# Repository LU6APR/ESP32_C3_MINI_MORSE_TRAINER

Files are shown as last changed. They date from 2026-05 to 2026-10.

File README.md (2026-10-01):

# ESP32_C3_MINI_MORSE_TRAINER
ESP32 C3 MINI MORSE TRAINER / OSCILATOR FOR IAMBIC KEYS

Keyer Iámbico + Decodificador CW con ESP32-C3 Mini
 Autor: LU6APR Pablo Ramos.
________________________________________
1. DESCRIPCIÓN DEL PROYECTO
Este proyecto consiste en la construcción de un Keyer Iámbico electrónico con decodificador de código Morse integrado, basado en el microcontrolador ESP32-C3 Super Mini.
El dispositivo permite:
•	Transmitir código Morse mediante una paleta iámbica (dos palancas: punto y raya)
•	Decodificar automáticamente el código Morse enviado
•	Mostrar el texto decodificado en una pantalla OLED (4 líneas)
•	Ajustar la velocidad de transmisión (WPM)
•	Espaciado automático después de 1 segundo de pausa
•	Borrado automático de pantalla al completar 4 líneas
•	Borrado manual con pulsación corta del botón

circuit_image

Copiar codigo en arduino ide, seleccionar puerto y ESP32 C3 mini, en mi caso use el LOLIN C3 MINI, compilar y subir al esp32 c3 mini.

Nota: el proyecto puede armarse sin la pantalla, y aun funcionara como oscilador para keys iambicos...

14/8/2026

<strong>LU5DZY</strong>, comparte circuito con opto acoplador al tx, por recomendacion en grupo de CW de colegas/amigos.
abajo el circuito. Grcs Nico!

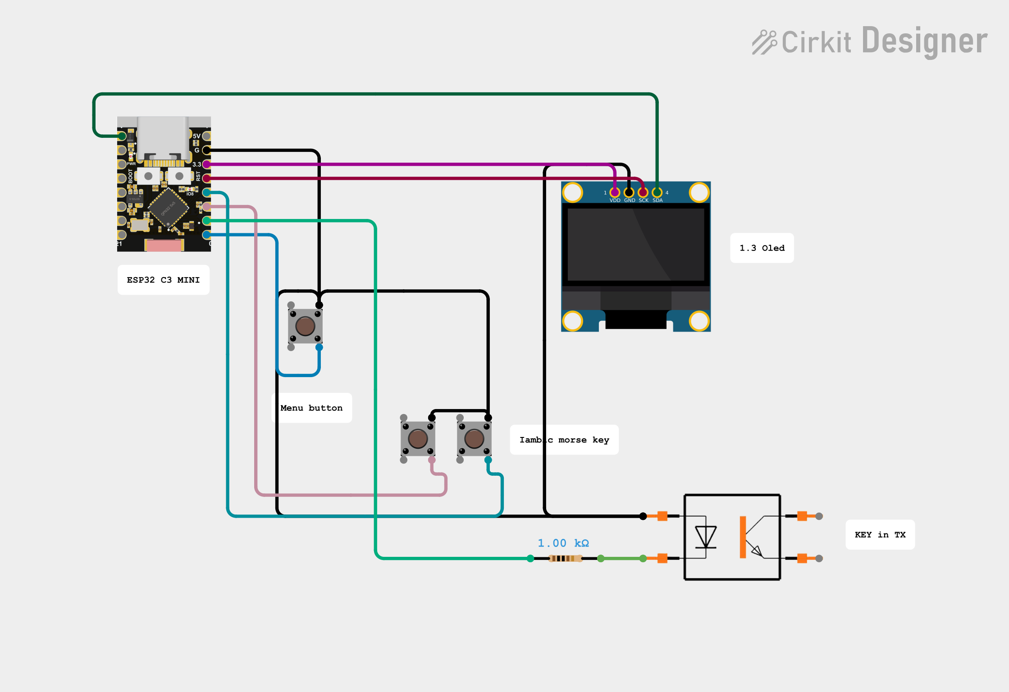
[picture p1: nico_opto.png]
circuit_image


Video: [LU5DZY_Opto.mp4](LU5DZY_Opto.mp4)

29/9/2026

<strong>PY3DU</strong>, comparte mejora en la seleccion de velocidad tocando boton y paddles para subir o bajar velocidad.
Disponible en la seccion de releases...

Video: [PY3DU_SPEED_CHANGE.mp4](PY3DU_spd_chng.mp4)

30/9/2026

<strong>LU6APR</strong>, Se convierte libreria de video a U8g2lib.h con la mejora en la seleccion de velocidad tocando boton y paddles para subir o bajar velocidad propuesta por PY3DU.
Disponible en la seccion de releases...

30/9/2026

<strong>PY3DU</strong>, comparte nueva mejora: escucha y repite y en la seleccion de velocidad tocando boton y paddles para subir o bajar velocidad.
Disponible en la seccion de releases...
 
Video: [PY3DU_game_listening.mp4](PY3DU_game_listening.mp4)

1/10/2026

<strong>PY3DU</strong>, comparte cambio de  salida de buzzer por  un parlante de 32 ohms.

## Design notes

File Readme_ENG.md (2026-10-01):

# ESP32_C3_MINI_MORSE_TRAINER
ESP32 C3 MINI MORSE TRAINER / OSCILLATOR FOR IAMBIC KEYS

Iambic Keyer + CW Decoder with ESP32-C3 Mini
 Author: LU6APR Pablo Ramos.
________________________________________
1. PROJECT DESCRIPTION
This project consists of building an electronic Iambic Keyer with an integrated Morse code decoder, based on the ESP32-C3 Super Mini microcontroller.
The device allows:
•	Transmitting Morse code using an iambic paddle (two levers: dot and dash)
•	Automatically decoding the transmitted Morse code
•	Displaying the decoded text on an OLED screen (4 lines)
•	Adjusting the transmission speed (WPM)
•	Automatic spacing after 1 second of pause
•	Automatic screen clearing when 4 lines are completed
•	Manual clearing with a short button press

circuit_image

Copy the code into the Arduino IDE, select the port and the ESP32 C3 mini (in my case I used the LOLIN C3 MINI), compile and upload it to the ESP32 C3 mini.

Note: the project can be assembled without the display, and it will still work as an oscillator for iambic keys...

14/8/2026

<strong>LU5DZY</strong> shared a circuit with an optocoupler to the TX, following a recommendation in a CW group of colleagues/friends.
The circuit is below. Thanks Nico!

circuit_image

Video: [LU5DZY_Opto.mp4](LU5DZY_Opto.mp4)

29/9/2026

<strong>PY3DU</strong>, Improved speed selection: now you can adjust it either by pressing the button or using the paddles (dits and dahs) to increase or decrease the speed. Thanks, Luiz! PY3DU.
Available in  releases...

Video: [PY3DU_SPEED_CHANGE.mp4](PY3DU_spd_chng.mp4)

30/9/2026

<strong>LU6APR</strong> The video library has been updated to U8g2lib.h  with the improvement in speed selection, allowing adjustment by pressing the button or using the paddles to increase or decrease the speed, as proposed by PY3DU. Available in the releases section...

01/10/2026

<strong>PY3DU</strong>, share an output with 32 ohms speaker replacing the buzzer.

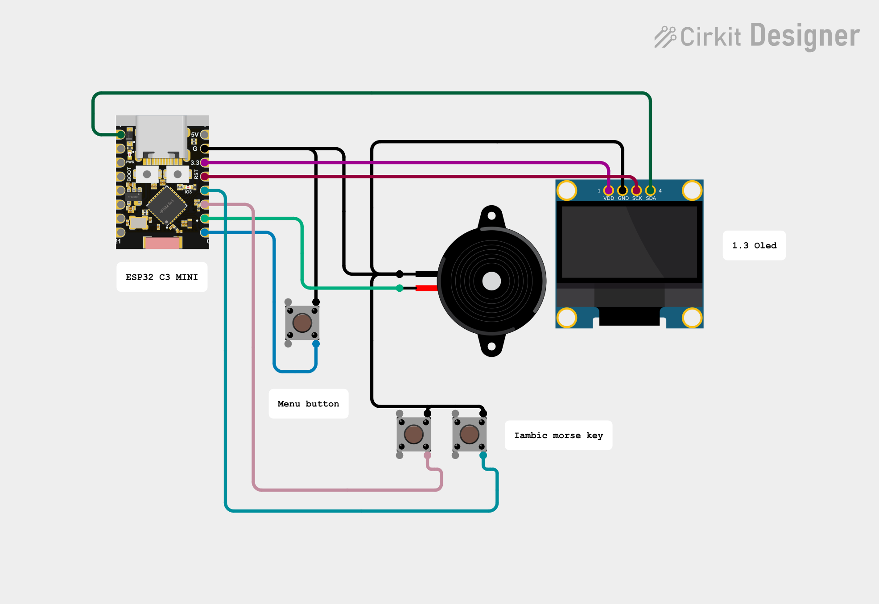
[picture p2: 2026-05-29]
circuit_image.png

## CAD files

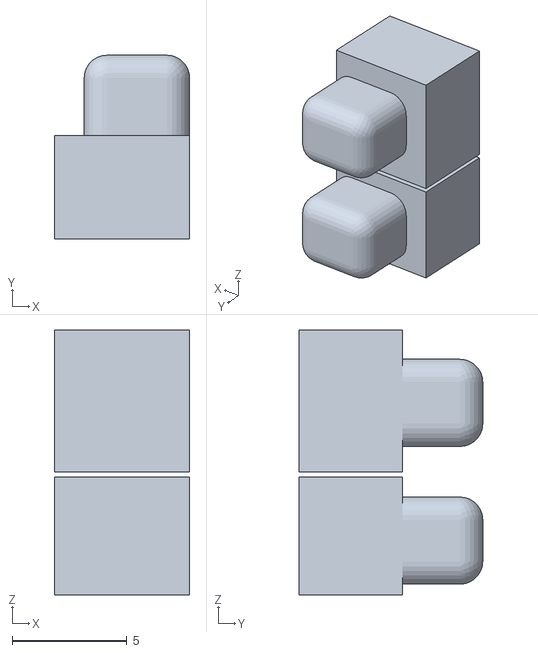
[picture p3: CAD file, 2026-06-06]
botones.stl
5.90 x 8.00 x 11.5

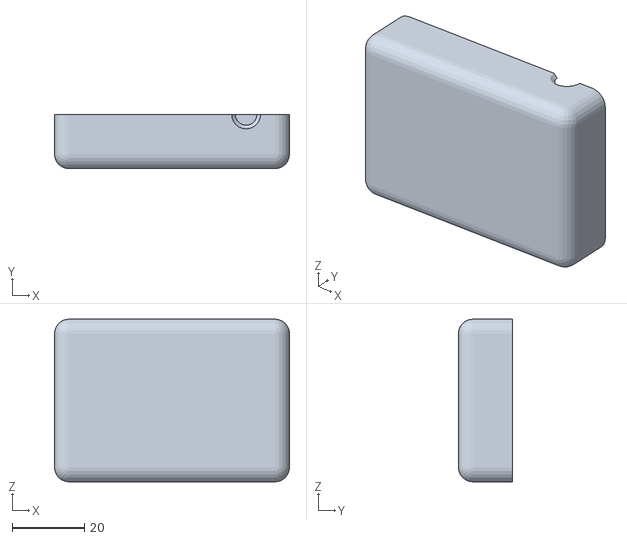
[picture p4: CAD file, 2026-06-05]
part2.stl
65.0 x 15.0 x 45.0

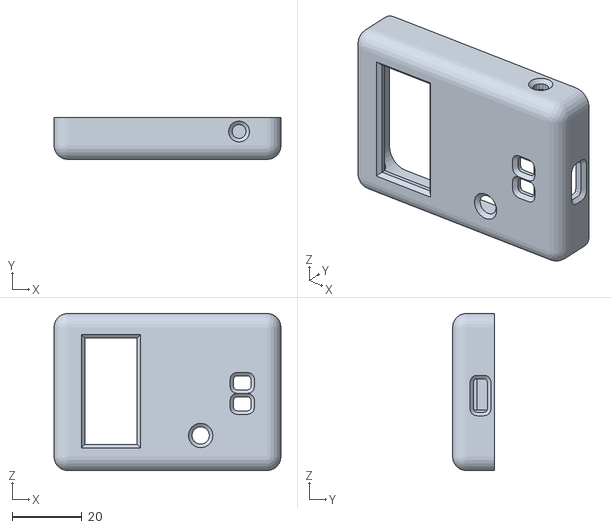
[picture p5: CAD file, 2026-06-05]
Part1.stl
65.0 x 12.0 x 45.0

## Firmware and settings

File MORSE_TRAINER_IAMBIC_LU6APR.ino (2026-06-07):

/*
  KEYER IÁMBICO LU6APR + DECODIFICADOR CW para ESP32-C3 Mini
  Pausa de 1 segundo para espacio automático
  Auto clear al llenar 4 líneas
*/

#include <Wire.h>
#include <U8g2lib.h>
#include <EEPROM.h>

// ==========================================
//   CONFIGURACIÓN DE PINES
// ==========================================
#define PIN_DIT         2
#define PIN_DAH         3
#define PIN_COMMAND     0
#define PIN_SIDETONE    1
#define PIN_KEY_OUT     6

#define I2C_SDA         5
#define I2C_SCL         4

// ==========================================
//   DISPLAY
// ==========================================
U8G2_SH1106_128X64_NONAME_F_HW_I2C u8g2(U8G2_R0, U8X8_PIN_NONE);

// ==========================================
//   CONFIGURACIÓN
// ==========================================
struct KeyerSettings {
  uint8_t speedWPM;
  bool iambicModeA;
  bool swapPaddles;
  bool sidetoneEnabled;
  uint16_t sidetoneFreq;
};

KeyerSettings settings = {15, true, false, true, 600};

// ==========================================
//   TABLA MORSE
// ==========================================
struct MorseChar {
  char character;
  uint8_t length;
  uint32_t code;
};

const MorseChar morseTable[] PROGMEM = {
  {'A',2,0b01},{'B',4,0b1000},{'C',4,0b1010},{'D',3,0b100},{'E',1,0b0},
  {'F',4,0b0010},{'G',3,0b110},{'H',4,0b0000},{'I',2,0b00},{'J',4,0b0111},
  {'K',3,0b101},{'L',4,0b0100},{'M',2,0b11},{'N',2,0b10},{'O',3,0b111},
  {'P',4,0b0110},{'Q',4,0b1101},{'R',3,0b010},{'S',3,0b000},{'T',1,0b1},
  {'U',3,0b001},{'V',4,0b0001},{'W',3,0b011},{'X',4,0b1001},{'Y',4,0b1011},
  {'Z',4,0b1100},{'0',5,0b11111},{'1',5,0b01111},{'2',5,0b00111},{'3',5,0b00011},
  {'4',5,0b00001},{'5',5,0b00000},{'6',5,0b10000},{'7',5,0b11000},{'8',5,0b11100},
  {'9',5,0b11110},{'.',6,0b010101},{',',6,0b110011},{'?',6,0b001100},{'!',6,0b101011},
  {';',6,0b101010},{':',6,0b111000},{'\'',6,0b011110},{'"',6,0b010110},{'-',6,0b100001},
  {'/',5,0b10010},{'=',5,0b10001},{'(',5,0b10110},{')',6,0b101101},{'@',6,0b110110},
  {'_',6,0b100110},{'+',5,0b01010},{'&',5,0b01000}
};

// ==========================================
//   VARIABLES
// ==========================================
#define MAX_TEXT_LENGTH 200
char textBuffer[MAX_TEXT_LENGTH];
uint16_t bufferStart = 0, bufferEnd = 0;
bool bufferFull = false;

uint32_t currentCode = 0;
uint8_t currentLength = 0;
unsigned long lastChangeTime = 0;
bool isKeyDown = false;
unsigned long keyDownStart = 0;

unsigned long lastKeyActivityTime = 0;
bool espacioAgregadoPorPausa = false;
const unsigned long PAUSA_ESPACIO_MS = 1000;

enum KeyerState { IDLE, DIT_PENDING, DAH_PENDING, KEY_DOWN, INTER_ELEMENT };
KeyerState keyerState = IDLE;
unsigned long keyerTimer = 0;
bool txActive = false;
volatile uint8_t paddleState = 0;
const uint8_t DIT_MASK = 0x01, DAH_MASK = 0x02;

bool lastBtnState = HIGH;
#define MAX_PANTALLA_CHARS 80
int caracteresEnPantalla = 0;

// ==========================================
//   FUNCIONES
// ==========================================
unsigned long getDitDuration() { return 1200UL / settings.speedWPM; }
unsigned long getDahDuration() { return getDitDuration() * 3; }
unsigned long getInterLetterGap() { return getDitDuration() * 3; }
unsigned long getInterWordGap() { return getDitDuration() * 7; }

void updateDisplay();

void addCharToBuffer(char c) {
  if (bufferFull) {
    textBuffer[bufferEnd] = c;
    bufferEnd = (bufferEnd + 1) % MAX_TEXT_LENGTH;
    bufferStart = bufferEnd;
    caracteresEnPantalla = MAX_PANTALLA_CHARS;
  } else {
    textBuffer[bufferEnd] = c;
    bufferEnd = (bufferEnd + 1) % MAX_TEXT_LENGTH;
    if (bufferEnd == bufferStart) bufferFull = true;
    caracteresEnPantalla++;
  }
  updateDisplay();
}

void addSpaceToBuffer() {
  if (bufferEnd != bufferStart || !bufferFull) addCharToBuffer(' ');
}

void clearBuffer() {
  bufferStart = 0; bufferEnd = 0; bufferFull = false;
  caracteresEnPantalla = 0;
  memset(textBuffer, 0, MAX_TEXT_LENGTH);
  updateDisplay();
}

void updateDisplay() {
  u8g2.firstPage();
  do {
    u8g2.setFont(u8g2_font_6x10_tf);
    uint16_t idx = bufferStart;
    for (int line = 0; line < 4; line++) {
      char lineBuffer[21] = {0};
      int col = 0;
      while (col < 20 && (idx != bufferEnd || bufferFull)) {
        char c = textBuffer[idx];
        if (c == '\0') c = ' ';
        lineBuffer[col++] = c;
        idx = (idx + 1) % MAX_TEXT_LENGTH;
        if (idx == bufferStart && !bufferFull) break;
      }
      u8g2.drawStr(0, 12 + (line * 12), lineBuffer);
    }
    char statusLine[25];
    sprintf(statusLine, "%dWPM %s", settings.speedWPM,
            settings.iambicModeA ? "IAM-A" : "IAM-B");
    u8g2.setFont(u8g2_font_5x7_tf);
    u8g2.drawStr(0, 58, statusLine);
  } while (u8g2.nextPage());
}

char decodeMorse(uint32_t code, uint8_t length) {
  int num = sizeof(morseTable) / sizeof(morseTable[0]);
  for (int i = 0; i < num; i++) {
    MorseChar mc;
    memcpy_P(&mc, &morseTable[i], sizeof(mc));
    if (mc.length == length && mc.code == code) return mc.character;
  }
  return '?';
}

void verificarPausaLarga() {
  if (!txActive && !isKeyDown) {
    if ((millis() - lastKeyActivityTime) >= PAUSA_ESPACIO_MS && !espacioAgregadoPorPausa) {
      addSpaceToBuffer();
      espacioAgregadoPorPausa = true;
      // BEEP ELIMINADO - Ya no suena al agregar espacio
    }
  } else {
    espacioAgregadoPorPausa = false;
  }
}

void verificarAutoClear() {
  if (caracteresEnPantalla >= MAX_PANTALLA_CHARS) {
    clearBuffer();
    const char* msg = ">CLEAR<";
    for (const char* p = msg; *p; p++) addCharToBuffer(*p);
    if (settings.sidetoneEnabled) {
      tone(PIN_SIDETONE, 1000); delay(60); noTone(PIN_SIDETONE);
      delay(40);
      tone(PIN_SIDETONE, 1200); delay(60); noTone(PIN_SIDETONE);
    }
  }
}

void processDecoder() {
  bool currentKeyState = digitalRead(PIN_KEY_OUT);
  unsigned long now = millis();
  
  if (currentKeyState && !isKeyDown) {
    isKeyDown = true; keyDownStart = now; lastKeyActivityTime = now;
    if (currentLength > 0 && (now - lastChangeTime) > getInterLetterGap()) {
      char c = decodeMorse(currentCode, currentLength);
      if (c != '\0') addCharToBuffer(c);
      currentCode = 0; currentLength = 0;
    }
  } else if (!currentKeyState && isKeyDown) {
    isKeyDown = false;
    unsigned long duration = now - keyDownStart;
    unsigned long ditDur = getDitDuration();
    lastKeyActivityTime = now;
    if (duration <= ditDur * 1.5) {
      currentCode = (currentCode << 1) | 0;
    } else if (duration <= ditDur * 3.5) {
      currentCode = (currentCode << 1) | 1;
    } else {
      currentCode = 0; currentLength = 0;
    }
    if (duration <= ditDur * 3.5) { currentLength++; if (currentLength > 12) currentLength = 12; }
    lastChangeTime = now;
  } else if (!isKeyDown && currentLength > 0) {
    if ((now - lastChangeTime) >= getInterLetterGap()) {
      char c = decodeMorse(currentCode, currentLength);
      if (c != '\0') addCharToBuffer(c);
      currentCode = 0; currentLength = 0; lastChangeTime = now;
    }
    if ((now - lastChangeTime) >= getInterWordGap()) {
      if (bufferEnd == 0 || textBuffer[(bufferEnd - 1 + MAX_TEXT_LENGTH) % MAX_TEXT_LENGTH] != ' ') {
        addSpaceToBuffer();
      }
      lastChangeTime = now;
    }
  }
  verificarPausaLarga();
  verificarAutoClear();
}

uint8_t readPaddles() {
  uint8_t result = 0;
  if (digitalRead(PIN_DIT) == LOW) result |= 0x01;
  if (digitalRead(PIN_DAH) == LOW) result |= 0x02;
  if (result) { lastKeyActivityTime = millis(); espacioAgregadoPorPausa = false; }
  if (settings.swapPaddles) {
    uint8_t swapped = 0;
    if (result & 0x01) swapped |= 0x02;
    if (result & 0x02) swapped |= 0x01;
    return swapped;
  }
  return result;
}

void startTransmit() {
  if (!txActive) {
    txActive = true;
    digitalWrite(PIN_KEY_OUT, HIGH);
    if (settings.sidetoneEnabled) tone(PIN_SIDETONE, settings.sidetoneFreq);
  }
}

void stopTransmit() {
  if (txActive) {
    txActive = false;
    digitalWrite(PIN_KEY_OUT, LOW);
    if (settings.sidetoneEnabled) noTone(PIN_SIDETONE);
  }
}

void processKeyer() {
  uint8_t paddles = readPaddles();
  unsigned long now = millis();
  switch (keyerState) {
    case IDLE:
      if (paddles & 0x01) { paddleState |= 0x01; keyerState = DIT_PENDING; }
      else if (paddles & 0x02) { paddleState |= 0x02; keyerState = DAH_PENDING; }
      break;
    case DIT_PENDING:
      if (paddleState & 0x01) { startTransmit(); keyerTimer = now + getDitDuration(); keyerState = KEY_DOWN; paddleState &= ~0x01; }
      else if (paddles & 0x02) { paddleState |= 0x02; keyerState = DAH_PENDING; }
      else keyerState = IDLE;
      break;
    case DAH_PENDING:
      if (paddleState & 0x02) { startTransmit(); keyerTimer = now + getDahDuration(); keyerState = KEY_DOWN; paddleState &= ~0x02; }
      else if (paddles & 0x01) { paddleState |= 0x01; keyerState = DIT_PENDING; }
      else keyerState = IDLE;
      break;
    case KEY_DOWN:
      if (now >= keyerTimer) { stopTransmit(); keyerTimer = now + getDitDuration(); keyerState = INTER_ELEMENT; if (!settings.iambicModeA) { uint8_t np = readPaddles(); if (np & 0x01) paddleState |= 0x01; if (np & 0x02) paddleState |= 0x02; } }
      break;
    case INTER_ELEMENT:
      if (now >= keyerTimer) {
        if (paddleState & 0x01) keyerState = DIT_PENDING;
        else if (paddleState & 0x02) keyerState = DAH_PENDING;
        else { uint8_t np = readPaddles(); if (np & 0x01) { paddleState |= 0x01; keyerState = DIT_PENDING; } else if (np & 0x02) { paddleState |= 0x02; keyerState = DAH_PENDING; } else keyerState = IDLE; }
      }
      break;
  }
}

void processCommand() {
  bool btnState = digitalRead(PIN_COMMAND);
  if (lastBtnState == HIGH && btnState == LOW) {
    unsigned long pressStart = millis();
    while (digitalRead(PIN_COMMAND) == LOW) delay(10);
    unsigned long duracion = millis() - pressStart;
    if (duracion < 1000) {
      clearBuffer();
      if (settings.sidetoneEnabled) { tone(PIN_SIDETONE, 800); delay(80); noTone(PIN_SIDETONE); }
    } else {
      settings.speedWPM += 5;
      if (settings.speedWPM > 35) settings.speedWPM = 10;
      EEPROM.begin(sizeof(settings) + 4);
      EEPROM.put(4, settings);
      EEPROM.commit();
      EEPROM.end();
      clearBuffer();
      char msg[8];
      sprintf(msg, "%dWPM", settings.speedWPM);
      for (char* p = msg; *p; p++) addCharToBuffer(*p);
      if (settings.sidetoneEnabled) { tone(PIN_SIDETONE, 1000); delay(100); noTone(PIN_SIDETONE); delay(50); tone(PIN_SIDETONE, 1000); delay(100); noTone(PIN_SIDETONE); }
    }
  }
  lastBtnState = btnState;
}

void showSplash() {
  u8g2.firstPage();
  do {
    u8g2.setFont(u8g2_font_ncenB14_tf);
    u8g2.drawStr(15, 30, "CW Trainer");
    u8g2.setFont(u8g2_font_6x10_tf);
    u8g2.drawStr(35, 50, "by LU6APR");
    u8g2.drawStr(42, 62, "(GP 3.0)");
  } while (u8g2.nextPage());
  delay(3000);
}

void setup() {
  pinMode(PIN_DIT, INPUT_PULLUP);
  pinMode(PIN_DAH, INPUT_PULLUP);
  pinMode(PIN_COMMAND, INPUT_PULLUP);
  pinMode(PIN_SIDETONE, OUTPUT);
  pinMode(PIN_KEY_OUT, OUTPUT);
  digitalWrite(PIN_KEY_OUT, LOW);
  
  EEPROM.begin(sizeof(settings) + 4);
  EEPROM.get(4, settings);
  if (settings.speedWPM < 5 || settings.speedWPM > 50) settings = {15, true, false, true, 600};
  EEPROM.end();
  
  Wire.begin(I2C_SDA, I2C_SCL);
  u8g2.begin();
  u8g2.setContrast(255);
  
  // Mostrar splash screen
  showSplash();
  
  lastKeyActivityTime = millis();
  clearBuffer();
  const char* inicio = ">READY<";
  for (const char* p = inicio; *p; p++) addCharToBuffer(*p);
  
  if (settings.sidetoneEnabled) { tone(PIN_SIDETONE, 600); delay(200); noTone(PIN_SIDETONE); }
}

void loop() {
  processKeyer();
  processDecoder();
  processCommand();
  delay(2);
}

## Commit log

2026-08-14 Update README with additional project details
    Added circuit image and notes for project setup.
2026-08-14 Add video link for LU5DZY Opto circuit
    Added a video link for LU5DZY Opto circuit demonstration.
